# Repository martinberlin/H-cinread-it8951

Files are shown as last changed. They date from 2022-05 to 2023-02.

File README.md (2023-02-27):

# DEXA-C097 ESP32S3 HAT

Hardware repository for Cinwrite PCB, a HAT for 9.7 inch parallel epaper display controller **DEXA-C097** sold by Good display which uses IT8951 as epaper timings controller and display engine.

This hardware is open source and you can use it commercially or modify it for your own purpouses according to the terms specified in the [License](https://github.com/martinberlin/H-cinread-it8951/blob/main/LICENSE). The only restriction is that it should be not mass produced and not sold without the permission of the Licensor.

License SVG

Licensed by:

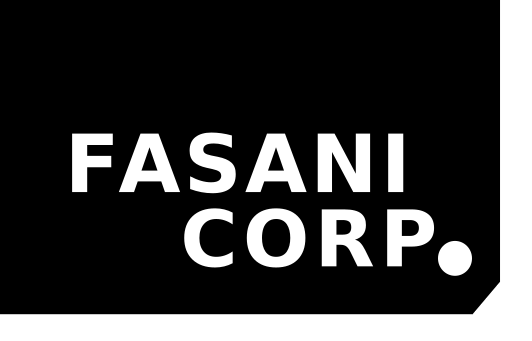
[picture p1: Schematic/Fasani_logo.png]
Fasani Corporation Logo


We only ask to be notified if you make a product based on this so we can showcase it as a success story. Collaborations and corrections on any terms including lowering consumption are welcome, please make an Issue, or feel free to contact me to the email in my github profile.

## OSHWA Certification UID [ES000029](https://certification.oshwa.org/es000029.html)

**The goal of this HAT is to provide:**

- WiFi
- BLE
- DS3231 real time clock
- Fast 40Mhz SPI
- 3V to 5V step-up
- 3.7v LiPo battery charger

You can get the produced and tested [Cinwrite board in Tindie](https://www.tindie.com/products/fasani/cinwrite-dexa-c097-hat-for-parallel-epapers) and at the same time you collaborate with our research.

## Where to get this

Even if you plan to send a batch for fabrication, we strongly recommend to get one first, so you collaborate with my work. But more importantly you can test the hardware to evaluate if it suits your project.
I don't have big quantities at the moment but you can get one at:

- [Lectronz FASANI store](https://lectronz.com/stores/fasani)
- https://www.tindie.com/stores/fasani

Both have similar prices. We can ship to all European countries and also to China mainland. Please check the hardware notices and also the DEXA-CO97 board from GOOD-DISPLAY if you want to drive a 1200x825 9.7" epaper display.

## Hardware notices

Cinread early revisions that Goodisplay is selling need a small very tiny bridge in the resistances at the side of SPI. Also the Silkscreen has an error and SI is swapped by CLK.
Please refer to the following image to the correct SPI labels:

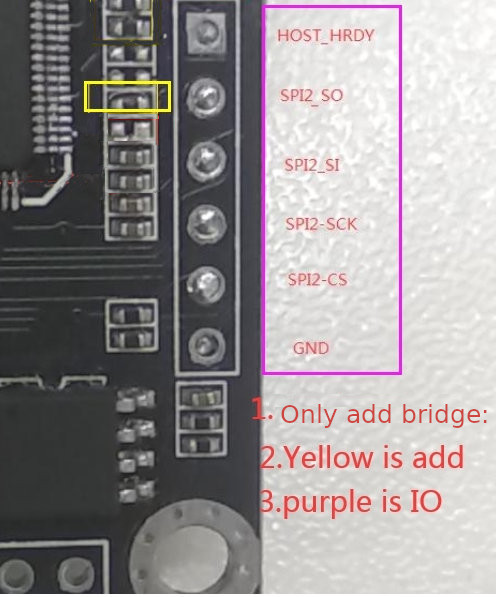
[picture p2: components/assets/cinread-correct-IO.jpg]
Corrected labels


Important: Please mind that the Cinread PCB has the SPI labels wrong. And that it needs a 0 Ω 0402 in the position marked as yellow. 6th counting from below at the SO Slave Output pin is please check the image carefully and place it in the right side. This will enable SPI.

UPDATE: On last point about the 0 Ω resistance just check that is there. But Good-Display is selling this with the hardware modification done so SPI should be running as it should.

## Ideas that could be added to the schematic

Provided by colleagues [Larry Bank](https://github.com/bitbank2) and [Lovyan03](https://github.com/lovyan03)

1) Increase the pull-up resistors from 2.2 to 4.7K. Safer if the external I2C device already has its own pullups. DONE
2) Add a voltage divider to measure the battery voltage. Something with one end connected to another GPIO to allow the current to be shut off completely when not needed. DONE
3) You might want to get a connector to connect a JTAG debugger. DONE

## ESP32-S3 Pin for JTAG

Referenced from this page in [Espressif documentation](https://docs.espressif.com/projects/esp-idf/en/latest/esp32s3/api-guides/jtag-debugging/configure-builtin-jtag.html)

```
GPIO19 D-

GPIO20 D+

5V -> V_BUS
```

This second USB will also enable DFU mode to flash the Microcontroller.

### Connection IOs used for preliminary tests

On my first tests to implement this using an Espressif ESP32-S3-WROOM-1U-N8R2 module with 2MB PSRAM I used the following GPIOs:

```
CONFIG_EINK_SPI_MOSI=11
CONFIG_EINK_SPI_MISO=12
CONFIG_EINK_SPI_CLK=13
CONFIG_EINK_SPI_CS=10
CONFIG_EINK_BUSY=3
```

Note: Reset PIN is not needed and it's also not in [Cinread PCB sold by Good display](https://www.good-display.com/product/425.html).

MISO pin should be connected and spi_3wire parameter for Lovyan GFX set to false, since it is in fact 4 wire SPI (CLK, MOSI, MISO)

This is using at the testing breadboard Lovyan GFX in their develop branch, since it reads the [mem_address to write the image from SPI](https://github.com/lovyan03/LovyanGFX/issues/242), hence using the master branch of the library it will not work or it will write the image incorrectly on the 9.7" display.

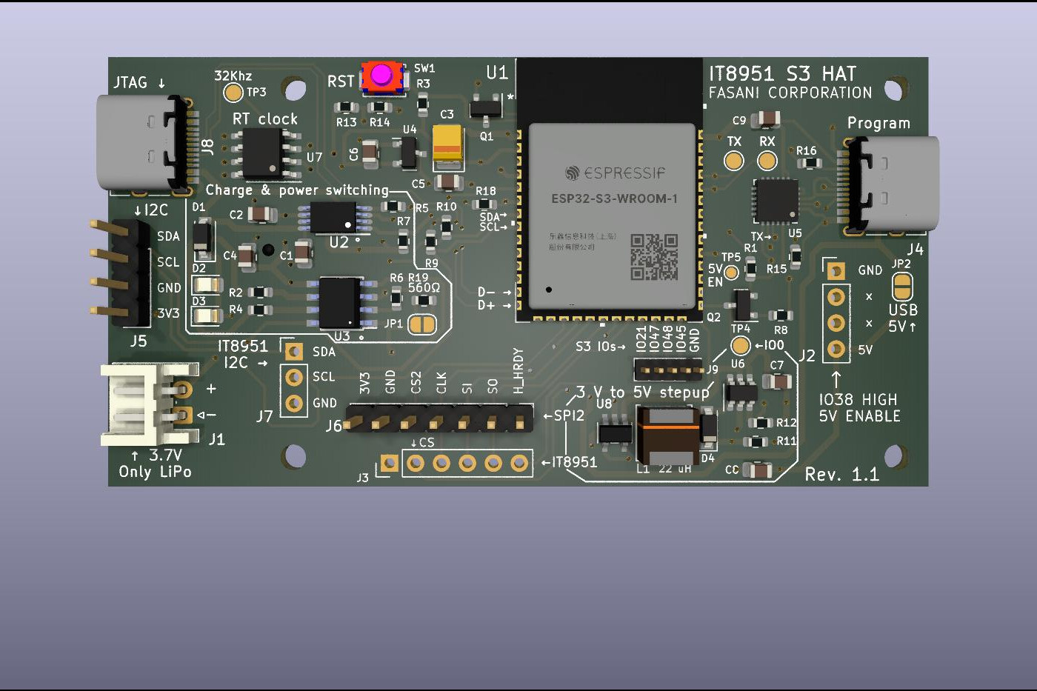
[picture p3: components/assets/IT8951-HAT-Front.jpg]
PCB front

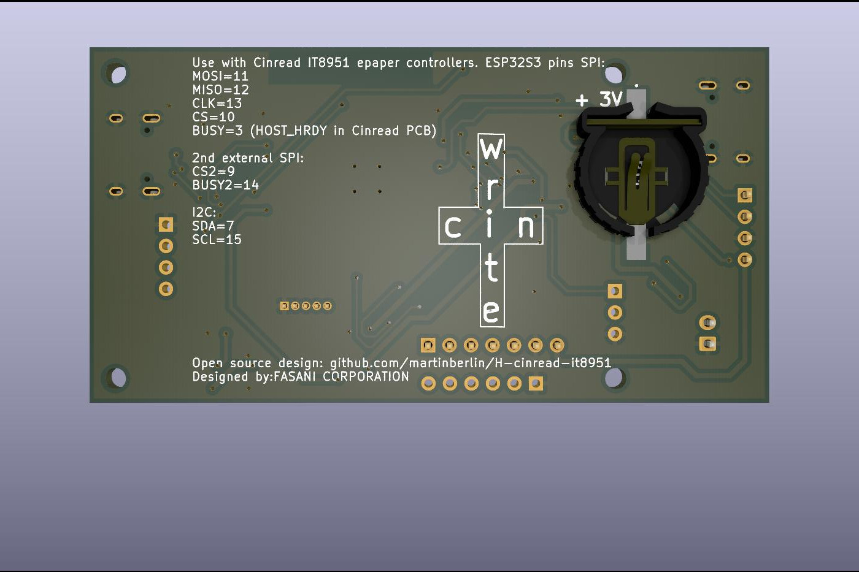
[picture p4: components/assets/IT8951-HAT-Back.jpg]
PCB back


### Hardware requirements

- [DEXA-C097](https://www.good-display.com/product/425.html) PCB sold by Good-Display
- One ED097OC* or **ED097TC2 parallel epaper**, sold by Aliexpress, check more [9.7" details in EPDiy project](https://github.com/vroland/epdiy#join-the-discussion) supported epapers table
- This board that is still on production.

In case you want to test it earlier, please get a ESP32-S3-WROOM-1U-N8R2 and connect the 4 required SPI cables, plus 5V and GND making your own PCB.

### Firmware examples

Meet [epaper weather station](https://github.com/martinberlin/epaper-weather-station) first project featuring this hardware and our test PCB.
epaper-weather-station-blurred

[Schematics](/Schematic/IT8951-S3-HAT-Schematic.pdf)

### Other hardware projects

- [Bistable-smart-switch](https://github.com/martinberlin/bistable-smart-switch) smart switch built with ESP32C3 and epaper display
- [SPI Adapters](https://github.com/martinberlin/H-spi-adapters) various SPI adapters and related PCBs

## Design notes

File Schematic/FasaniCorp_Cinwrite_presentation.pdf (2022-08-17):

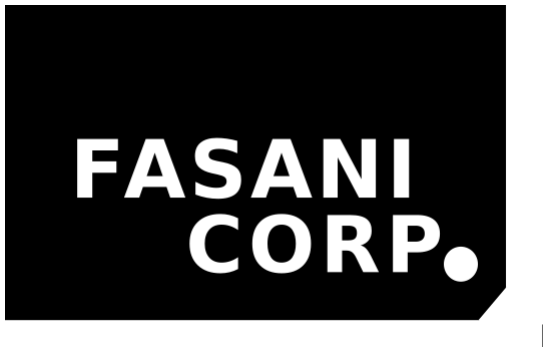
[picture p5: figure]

DEXA-C097 ESP32S3 HAT

This PCB mission is to provide:

- ESP32S3 Espressif MCU with 2MB of external RAM
- WiFi
- BLE
- DS3231 real time clock and small CR1220 coin battery to keep time
- Fast 40Mhz SPI
- 3V to 5V step-up (And a way to enable this boost converter)
- 3.7v LiPo battery charger
- I2C connector for sensors
- Extra SPI connector with it’s own Busy & Chip select pin

You can find more about the Schematic, BOM and PCB Routing in the following link:

https://github.com/martinberlin/H-cinread-it8951
This is an open source designed Hardware so the goal is that other developers can collaborate, make merge requests to add new features, or fork it and send to fabrication their own version provided the LICENSE is respected and does not go to mass production.

APPLICATION IDEAS
Wall digital clock with temperature, Photo-frame that receives image per Bluetooth, sensors that connect per I2C or SPI and display useful information. WiFi download of API information to the epaper display, etc.

CURRENT KNOWN ISSUES
- Charges battery too strong: This will make the Tp4056 and the diode heat, making the RTC temperature measurements go 10°C or more degrees hot. You might disconnect JP1 jumper for a slower charge.
- I2C connection with board below does block I2C in V1.0 since it has a wrong pin-up. It’s solved in the v1.1 version that is the only one that we are producing.
SOLUTION: Do not connect SDA, SCL pins to board below if the PCB version is < 1.1

VCOM Setting this value via LovyanGFX library using SPI communication on this board is working but having unexpected behavior that is not caused by my PCB.
HENCE, the VCOM printed in my demo, is the default which is too high for most EPAPERS being 2600 ( -2.6 V)

This project has applied for oshwa.org open source certification and we plan to keep all design files, documentation and demo software in this format.

FASANI CORP. | DEXA-C097 ESP32S3 HAT version 1.1 | www.fasani.de
1

# PIN UP Table

Description | Protocol | Out/Input in MCU | GPIO number
MOSI | SPI | OUT | 11
MISO | SPI | IN | 12
CLK | SPI | OUT | 13
CS | SPI | OUT | 10
BUSY | SPI | IN | 3
MOSI/MISO/CLK | Shared SPI1 & SPI2 | - - - | - - -
CS2 | SPI 2 | OUT | 9
BUSY2 | SPI 2 | IN | 14
SDA | I2C | Bidirectional | 7
SCL | I2C | OUT | 15
ENABLE_5V | - - - | OUT | 38
ADC1_CH3 | To measure battery | IN to ADC | 4
TPS_STAT | Power by USB (LOW) Battery (HIGH) | IN | 5
DS3231_INT | Interrupt pin from RTC w/pull-up | IN | 6
Extra GPIOS for | Buttons / sensors:
IO21 | Below MCU | Per Firmware decide | 21
IO45 | | | 45
IO47 | | | 47
IO48 | | | 48

Martin Fasani, last revised on Barcelona 17.Aug.2022

FASANI CORP. | DEXA-C097 ESP32S3 HAT version 1.1 | www.fasani.de
2

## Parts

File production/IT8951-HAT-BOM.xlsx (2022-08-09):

Designator | Footprint | Comment | JLCPCB Part #
U3 | TP4056_SOP-8-PP | TP4056 | C16581
C4,C2,C1 | C_0805_2012Metric | 100nF | C49678
Q1,Q2 | SOT-23 | BC817 | C146798
D1,D4 | D_SOD-123 | 1N5817 | C8598
C3 | CP_EIA-3528-21_Kemet-B | C_Polarized 100uF | C129289
C7,C8 | C_0805_2012Metric | 22uF | C602037
R14 | R_0603_1608Metric | 160K | C22813
R8,R3,R1,R18,R7 | R_0603_1608Metric | 10 K | C25804
L1 | SWPA5040S282MT | 22 uH | C68434
R11 | R_0603_1608Metric | 110K | C25805
R16,R15 | R_0603_1608Metric | 5.1K | C23186
D2 | LED_0805_2012Metric | GRE | C2297
U7 | SOIC-8_3.9x4.9mm_P1.27mm | DS3231MZ | C107410
C5,C6 | C_0805_2012Metric | 10uF | C15850
R12 | R_0603_1608Metric | 15K | C22809
D3 | LED_0805_2012Metric | RED | C84256
R5 | R_0603_1608Metric | 400 | C23151
U1 | ESP32-S3-WROOM-1-N8 | ESP32-S3-WROOM-1-N8
U2 | TPS2113APW | TPS2113APWR
U8 | AP22802AW5-7 | AP22802AW5-7 | C211404
R19 | R_0603_1608Metric | 560Ω | C23204
J8 | USB_C_Receptacle_HRO_TYPE-C-31-M-12 | USB_C_JTAG | C165948
R9,R10 | R_0603_1608Metric | 4.7K | C23162
U5 | QFN-24-1EP_4x4mm_P0.5mm_EP2.6x2.6mm | CP2102N-Axx-xQFN24 | C969151
J4 | USB_C_Receptacle_HRO_TYPE-C-31-M-12 | USB_C_Programming | C165948
SW1 | Alps_SKRK | RESET | C202388
R6 | R_0603_1608Metric | 680Ω | C23228
R2,R4 | R_0603_1608Metric | 5K | C23046
U4 | SOT-23 | MCP1700-3302E_SOT23 | C39051
U6 | SOT-23-6 | MT3608 | C2932326
R13 | R_0603_1608Metric | 442K | C23175
C9 | C_0805_2012Metric | 100 nF | C28233

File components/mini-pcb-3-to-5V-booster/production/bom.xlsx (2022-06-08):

Designator | Footprint | Comment | JLCPCB Part #
L1 | SWPA5040S282MT | 22uH | C68434
C2,C1 | C_0805_2012Metric | 22uF | C1644
R1 | R_0603_1608Metric | 110K | C25805
R2 | R_0603_1608Metric | 15K | C22809
D1 | D_SOD-123 | 1N5817 | C8598
U1 | SOT-23-6 | MT3608 | C2932326

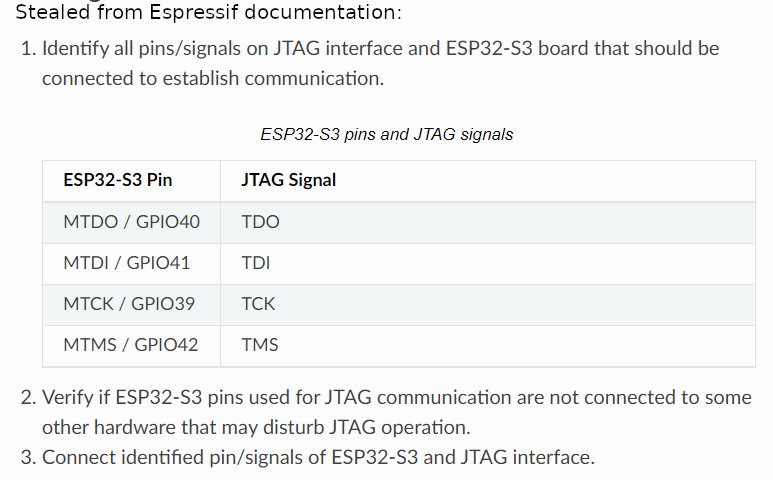
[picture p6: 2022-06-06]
components/assets/jtag.png

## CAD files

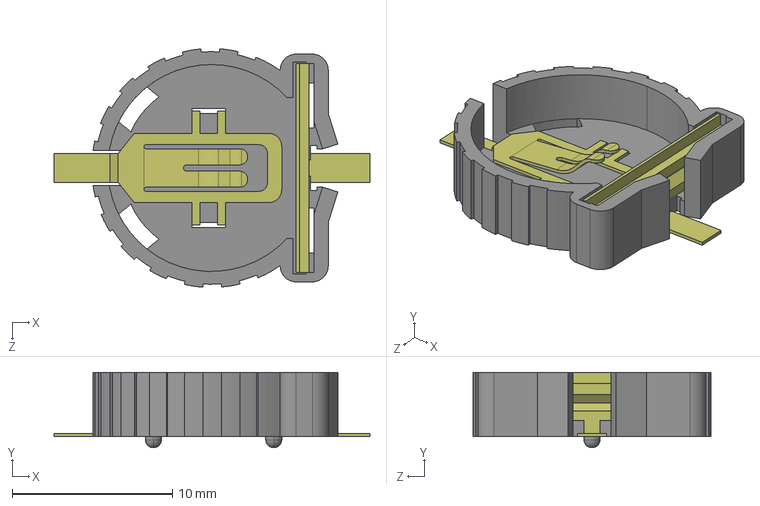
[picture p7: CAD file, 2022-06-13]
components/3d/CR1220-2.step
19.7 x 4.70 x 14.9 mm

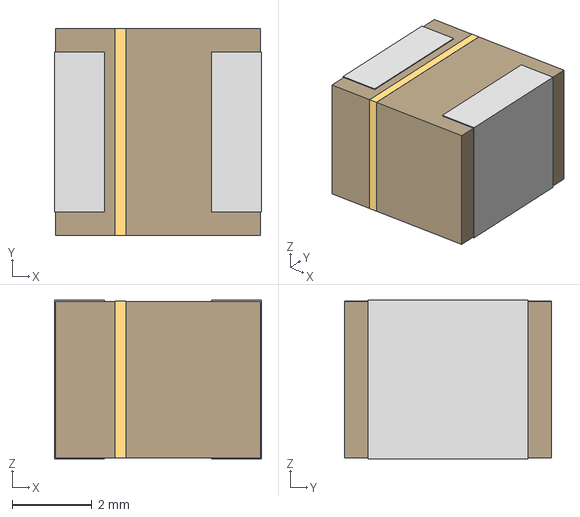
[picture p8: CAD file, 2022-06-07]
components/3d/IND_0S282MT_SNL.step
5.21 x 5.21 x 3.99 mm

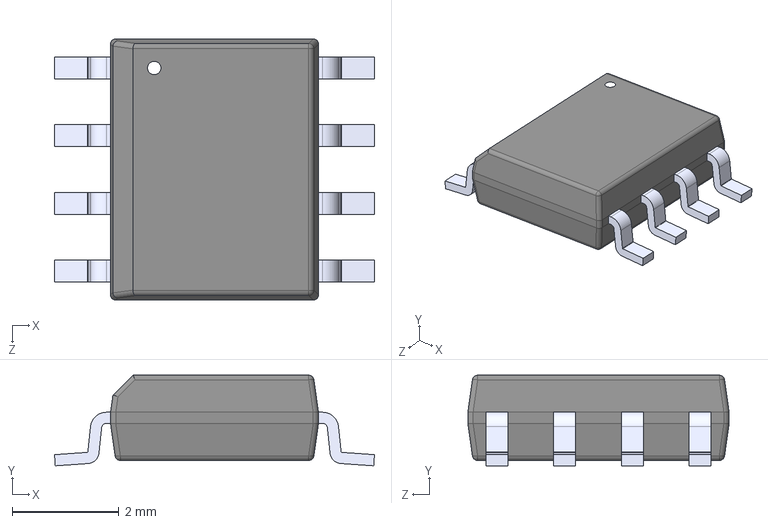
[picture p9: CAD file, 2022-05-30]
components/3d/TP4056.step
6.00 x 1.70 x 4.90 mm

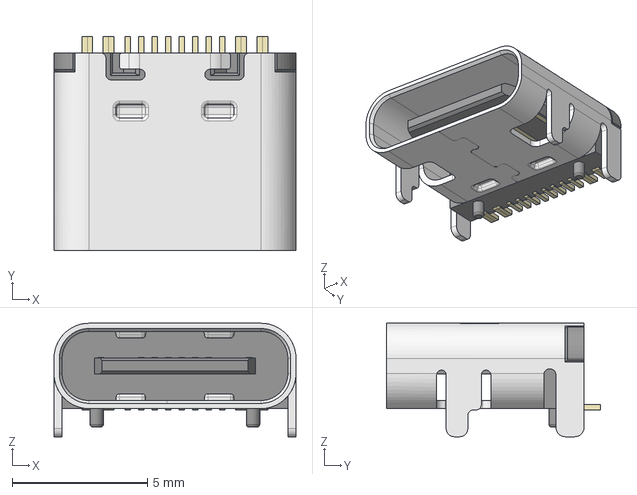
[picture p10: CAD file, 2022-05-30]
components/3d/HRO_TYPE-C-31-M-12.step
8.95 x 7.90 x 4.20 mm

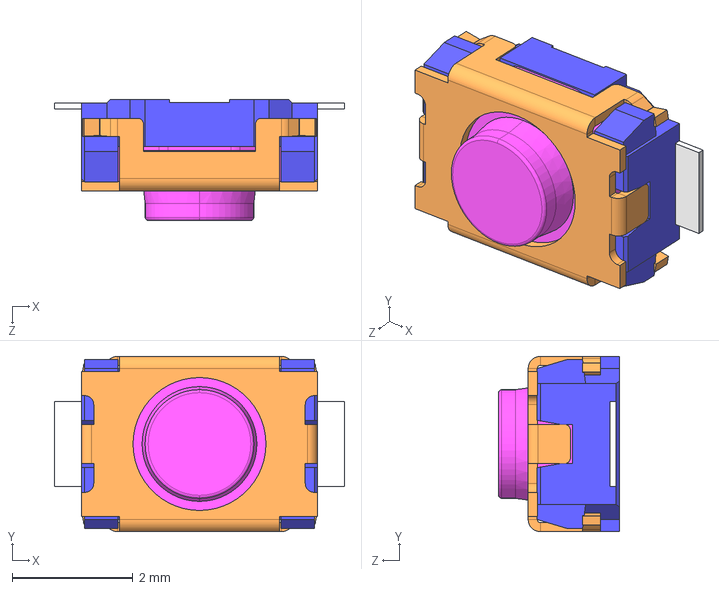
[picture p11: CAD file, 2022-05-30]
components/3d/Button_SKRKAH.step
4.80 x 2.90 x 2.00 mm

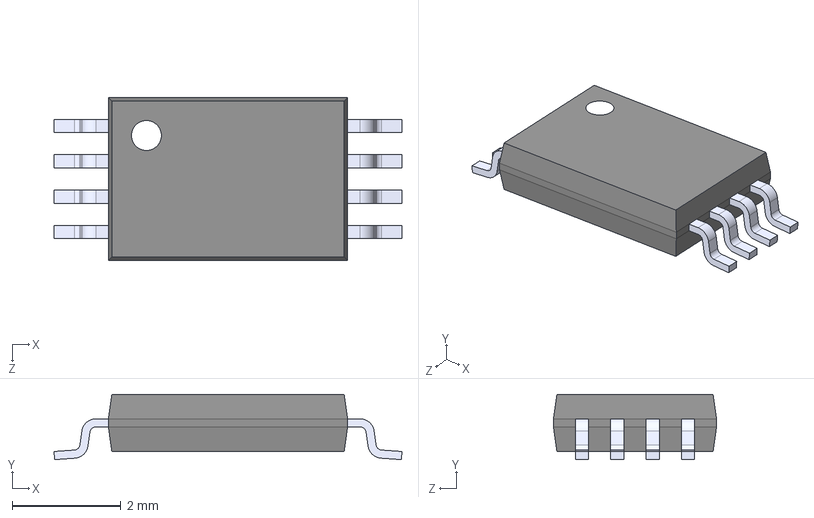
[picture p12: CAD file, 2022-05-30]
components/3d/tps2113apwr.step
6.40 x 1.20 x 3.00 mm

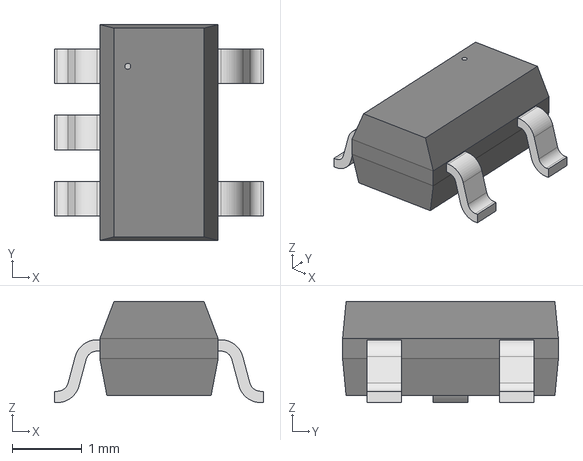
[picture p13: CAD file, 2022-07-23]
components/3d/AP22802AW5-7.step
3.00 x 3.10 x 1.45 mm

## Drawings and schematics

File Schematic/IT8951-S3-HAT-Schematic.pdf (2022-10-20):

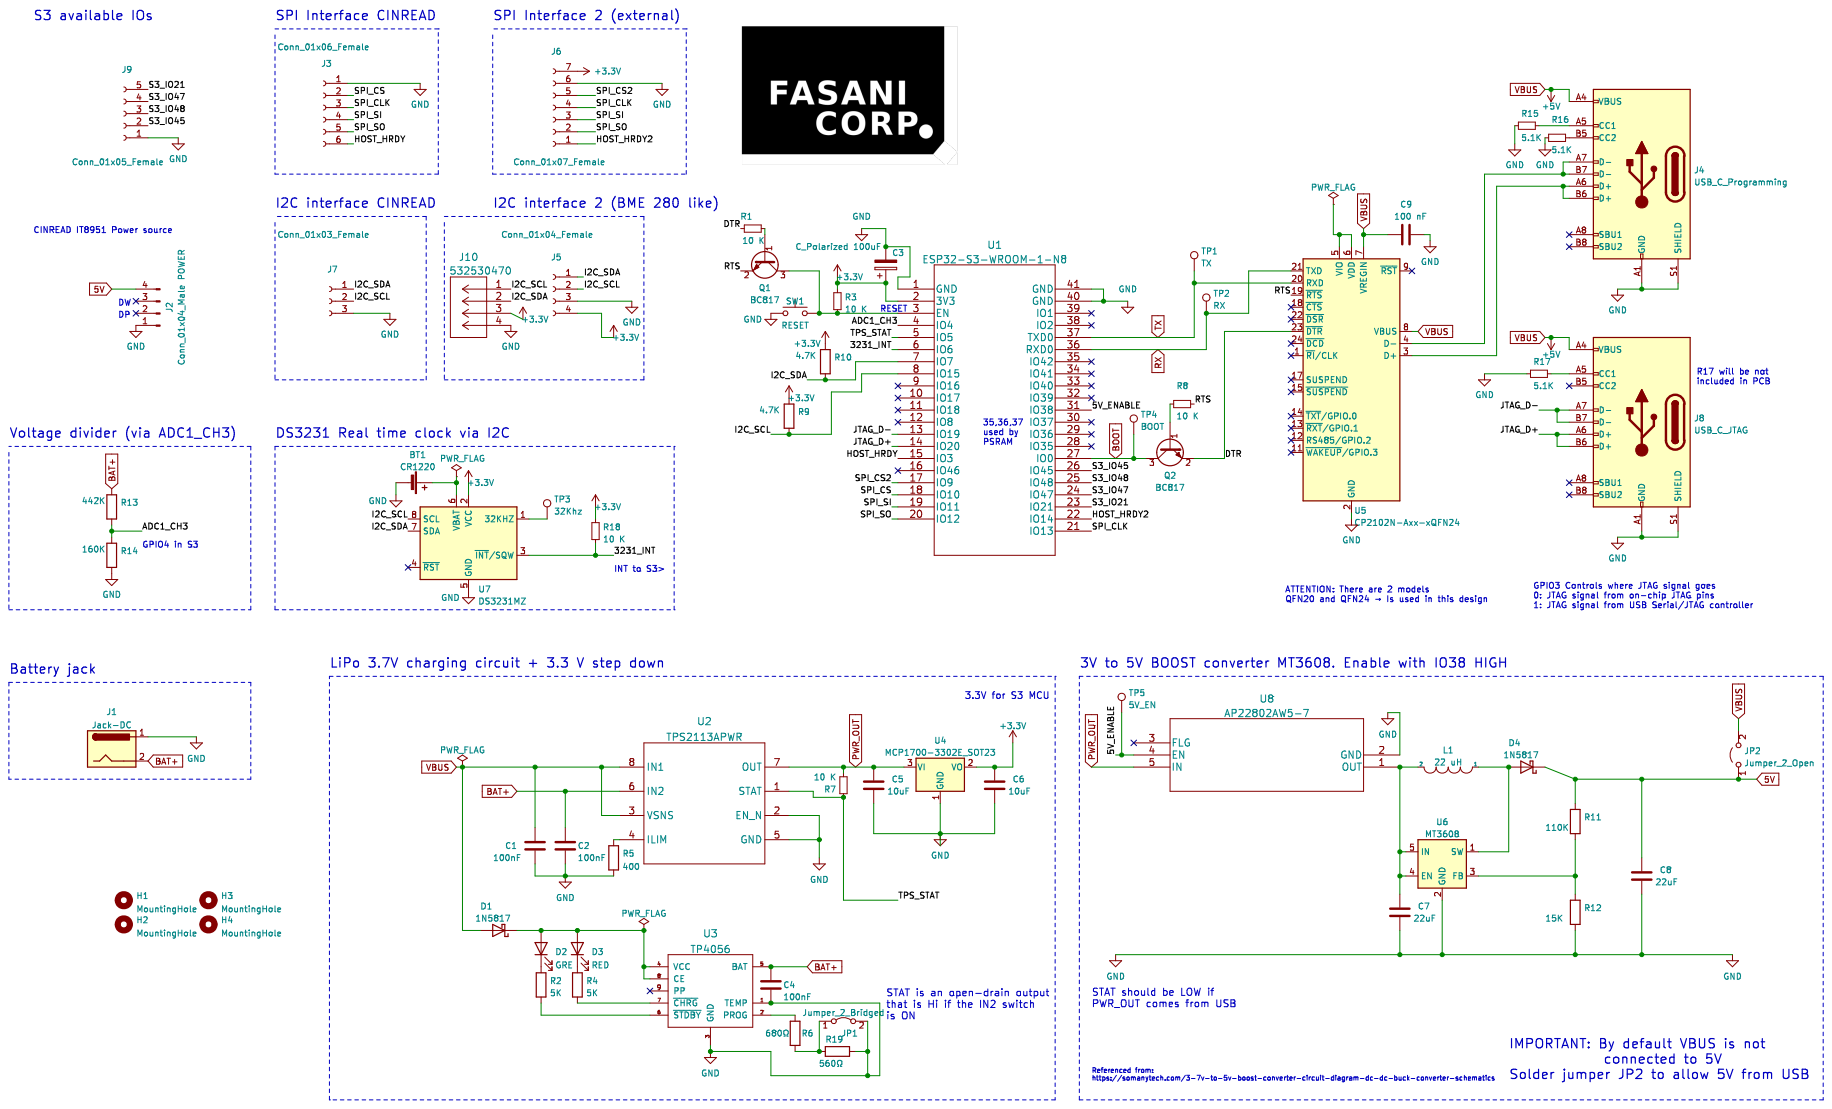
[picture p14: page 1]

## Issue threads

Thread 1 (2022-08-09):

S2 budget price PCB version

martinberlin, 2022-08-09:
If you want me to design a cheaper version of this PCB, that is stepped down in MCU and uses cheaper but capable of the same thing chips (Like a bigger [DS3231](https://jlcpcb.com/partdetail/MaximIntegrated-DS3231M/C1520508) with 16 legs that cost 2$ instead of 9$ smaller one)

Then just reply to this Issue or add a positive thumbs up.

The step down will mostly affect MCU and DS3231, other things will keep the same quality as before:

- ESP32-S2-WROVER with PSRAM (Soldered by hand, all others in JLCPCB)
- DS3231 RTC with same capabilities than the more expensive version

If there is at least some people interested then I will go for it and spend my time making a new PCB in S2 branch.

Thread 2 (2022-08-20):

Make a version that will support Waveshare IT8951 boards

martinberlin, 2022-08-20:
Note: This board we use just SPI, not with Raspberry PI:
https://www.waveshare.com/product/displays/e-paper/epaper-1/9.7inch-e-paper-hat.htm

If you are interested please add your **thumbs up**!

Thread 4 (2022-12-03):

Make a wiser selection for extra GPIOs

martinberlin, 2022-12-03:
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
From the current 4 additional IOs offered, only one (21) is an RTC GPIO, which is quite annoying if you would like to have 3 buttons that need to be RTC. At least 3 of this four IOs should be RTC IMHO.

And it would be also a great idea if this unconventional 1x05_P1.27mm pin header is transformed into a Grove connector or another connector with the possibility to route all free IOs in order to make the most of the ESP32S3 project

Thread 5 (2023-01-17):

What is the power consumption of IT8951?

lanistor, 2023-01-17:
In some forums, I saw that the IT8951 consumes a lot of power and cannot be powered off.

martinberlin, 2023-01-17:
It's not really on the documentation since I guess depends what display drives.
Yes of you can power it off, please check this PCB, that I use to drive it.
After all updates the 5V power goes down completely. There is a spike at the beginning when the 5V boost converter starts and then consumes between 150 and 200 ms while it's delivering the update.
My PCB's will for some time discounted at https://lectronz.com/stores/fasani but the Cinread DEXA module you need to get it via Good Display ( freddie@good-display.com )

Tell him that I referenced you to get a better price.

gooddisplayepaper, 2023-01-18:
https://twitter.com/i/status/1615548322567319558
Here this video for you see testing points readings.

lanistor, 2023-01-18:
>

@martinberlin  @gooddisplayepaper  Thanks a lot, we are consider this solution, but we are worried about the performance of ESP32-S3, we use ESP32 now but it computed slowly with lvgl([issue](https://github.com/lvgl/lvgl/issues/3921)), we don't know if this will happen on this solution.

martinberlin, 2023-01-19:
Get one and give it a try. @gooddisplayepaper could you sent one of your Cinwrite boards to them if they finish the purchase so it arrives faster? (I will restock it to you in next sending)
@lanistor note that if they send it faster from there you have to soldier female headers. I usually do it this way:

Add female headers on the HAT. Put the male 2.54 headers looking up over the DEXA board and then turn it around to soldier.
This makes that both PCB's are connected gracefully and without force. Please note: Only SPI pins should be connected, leave I2C disconnected, since we don't use I2C communication with DEXA (All SPI master)
SPI master works very fast with S3 and partial updates using Lovyan GFX library also worked good for us.

lanistor, 2023-01-20:
>

Full screen refresh nearly 2 seconds, it's OK. Thanks @martinberlin

May you send me a Cinwrite board, it can save our development time, thanks so much.

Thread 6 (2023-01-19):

Can this board on shop send to China?

lanistor, 2023-01-19:
I see it on `tindie`, can it send to China? Or any other platform such as `Amazon`.

martinberlin, 2023-01-19:
Hi Lanistor,
Yes sure I can send it just added a very fair price to you in Tindie. If you prefer to

**One question:** Would you prefer me to send you one that has already female headers soldered?
I will also solder the RTC backup battery (Needs a CR1220, that is not included, and it's useful so time is kept while you debug)

Please contact Freddie from @gooddisplayepaper for the Cinwrite board. Also if there is interest in China we could make a batch to sell directly from there then it will be quite faster the delivery (Takes almost 3 weeks each time I send something)
I also started another store in a new site that is called Lectronz, however this ones do not accept PayPal, they use only Stripe as payment method:
https://lectronz.com/stores/fasani

Just let me know or contact me per email if you have any special request. Thanks for contributing to open source hardware

lanistor, 2023-01-20:
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

Thanks a lot, hope @gooddisplayepaper can send me one Cinwrite board.

gooddisplayepaper, 2023-01-21:
Hello, would you please email to freddie@good-display.com ? Get me the shipping details and since this won't be a free sample request (I can give you discount and free shipping) I might issue you a proforma invoice and to be shipped after 29th Jan

gooddisplayepaper, 2023-02-01:
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

Hello Lanistor, is it possible we continue to talk on Email mine is freddie@good-display.com Sent you email again plz check.

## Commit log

2022-05-30 Update License and add components
    [HRO_TYPE-C-31-M-12.step, SKRKAH.STEP, TP4056.step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]
2022-05-31 Start with schematic
    [IT8951-HAT.kicad_sch]
2022-05-31 Add v1 Schema
    [IT8951-HAT.kicad_sch]
2022-06-03 Update schematic with new 5V BOOST converter
    [IT8951-HAT.kicad_sch]
2022-06-03 Add ext. SPI & I2C interface
    [IT8951-HAT.kicad_sch]
2022-06-03 Add LCSC meta info
    [IT8951-HAT.kicad_sch]
2022-06-05 I2C Pins confirmed to work in prototype
    [IT8951-HAT.kicad_sch]
2022-06-06 Add suggested ideas to Readme
    [IT8951-HAT.kicad_sch]
2022-06-07 Start with PCB part
    [IND_0S282MT_SNL.step, IT8951-HAT.kicad_pcb, IT8951-HAT.kicad_sch]
2022-06-08 Routing v1.0
    [IT8951-HAT.kicad_pcb, IT8951-HAT.kicad_sch, bom.xlsx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]
2022-06-11 Add Voltage divider to ADC channel 3 (IO 4)
    [IT8951-HAT.kicad_pcb, IT8951-HAT.kicad_sch]
2022-06-13 Update schematic with RTC
    [Button_SKRKAH.step]
2022-06-13 Route RTC DS3231MZ
    [CR1220-2.step, IT8951-HAT.kicad_pcb, IT8951-HAT.kicad_sch]
2022-06-13 Antenna needs a Keep out zone
    [IT8951-HAT.kicad_pcb]
2022-06-13 Add pull down RES to CC* lines in USBC
    [IT8951-HAT.kicad_pcb, IT8951-HAT.kicad_sch]
2022-06-14 Minimal intervention on JTAG D* lines
    [IT8951-HAT.kicad_pcb]
2022-06-15 HOST_HRDY2 needs to be an independent IO
    [IT8951-HAT.kicad_pcb, IT8951-HAT.kicad_sch]
2022-06-15 Add 3V3 and external 4 IO additional connectors
    [IT8951-HAT.kicad_pcb, IT8951-HAT.kicad_sch]
2022-06-15 Add some preview imgs
    [IT8951-HAT.kicad_pcb]
2022-06-16 Add additional 5.1K RES to JTAG
    [IT8951-HAT.kicad_pcb, IT8951-HAT.kicad_sch]
2022-06-16 Add pullup RES to DS3231 INT
    [IT8951-HAT.kicad_pcb, IT8951-HAT.kicad_sch]
2022-06-28 Latest test before production
    [IT8951-HAT.kicad_pcb, IT8951-HAT.kicad_sch, mini-pcb-3-to-5V-booster.kicad_sch]
2022-06-28 Update schematic PDF
2022-06-29 Update the reference to JTAG pins
    [IT8951-HAT.kicad_pcb]
2022-07-01 Add 5V_ENABLE in GPIO38 (Consumption)
    [IT8951-HAT.kicad_pcb, IT8951-HAT.kicad_sch]
2022-07-03 REV 1.0 sent to fabrication
    [IT8951-HAT.kicad_pcb, IT8951-HAT.kicad_sch]
2022-07-04 Add BOM
    [IT8951-HAT-BOM.xlsx]
2022-07-15 CP2102 wiring TX->RX RX->TX check UART before fabrication
    [IT8951-HAT.kicad_pcb, IT8951-HAT.kicad_sch]
2022-07-17 Update schematic
2022-07-22 First push to V1.1 PWR_OUT should come from TPS2113 PWR manager
    [IT8951-HAT.kicad_pcb, IT8951-HAT.kicad_sch]
2022-07-23 Add AP22802AW5-7 load switch
    [AP22802AW5-7.step]
2022-07-24 Add routing for AP22802AW5 (Enabled on IO38 HIGH)
    [IT8951-HAT.kicad_pcb, IT8951-HAT.kicad_sch]
2022-07-24 VBUS needs to flow to IN1 in TPS2113
    [IT8951-HAT.kicad_pcb, IT8951-HAT.kicad_sch]
2022-07-24 Make VBUS width 6mm
    [IT8951-HAT.kicad_pcb]
2022-07-26 Improve I2C routing
    [IT8951-HAT.kicad_pcb]
2022-07-26 Add +3V label in Back silkscreen (RTC coin battery)
    [IT8951-HAT.kicad_pcb]
2022-07-28 I2C SCH & PCB routing: SDA & GND where swapped this is right order
    [IT8951-HAT.kicad_pcb, IT8951-HAT.kicad_sch]
2022-08-03 1.1.1 Move load switch to IN side of boost conv.
    [IT8951-HAT.kicad_pcb, IT8951-HAT.kicad_sch]
2022-08-09 Add link in readme to S2 idea. Update 3D views
    [IT8951-HAT-BOM.xlsx, IT8951-HAT.kicad_pcb, IT8951-HAT.kicad_sch]
2022-08-15 Add one page presentation + Logo
    [IT8951-HAT.kicad_sch]
2022-08-15 New LOGO
    [IT8951-HAT.kicad_sch]
2022-08-17 Update with I2C comments
2022-08-19 Update License and add to kicad_sch
    [IT8951-HAT.kicad_sch]
2022-10-06 Add Grove I2C connector
    [IT8951-HAT.kicad_pcb, IT8951-HAT.kicad_sch]
2022-10-06 Update Silk + reposition parts
    [IT8951-HAT.kicad_pcb]
2022-10-07 Last updates to v1.2
    [IT8951-HAT.kicad_pcb]
2022-10-20 Update 1.2 Schematic
2023-01-23 Update README.md
    Correction about 0Ω RES
